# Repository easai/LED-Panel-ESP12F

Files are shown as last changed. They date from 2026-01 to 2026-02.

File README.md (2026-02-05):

# LED Panel ESP‑12F

The HTML page is available in this GitHub repository:
[https://easai.github.io/LED-Panel-ESP12F/](https://easai.github.io/LED-Panel-ESP12F/)

A compact ESP‑12F–based controller board designed to drive an 8×8 LED panel with an onboard buzzer, stable power regulation, and reliable programming support. This project was completed with the generous support of my sponsor, whose fabrication assistance transformed a fragile prototype into a robust, reproducible hardware platform.

## Sponsor Acknowledgment

This project reached completion thanks to the support of <a href="https://www.pcbway.com/" target="_blank" title="PCBWay">PCBWay</a>, who provided fabrication assistance that transformed the prototype into a clean, reliable PCB. Before fabrication, the prototype relied on a dense web of jumper wires, loose connections, and constant troubleshooting. With my sponsor’s help, the design moved from that unstable setup to a clean, professionally manufactured PCB that is easy to assemble, reliable to operate, and ready for long‑term use.

Their contribution directly improved electrical stability, mechanical reliability, assembly clarity, and long‑term maintainability. The contrast between the prototype and the final board demonstrates the real value of proper PCB fabrication.

## Breadboard Prototype → PCB Assembly

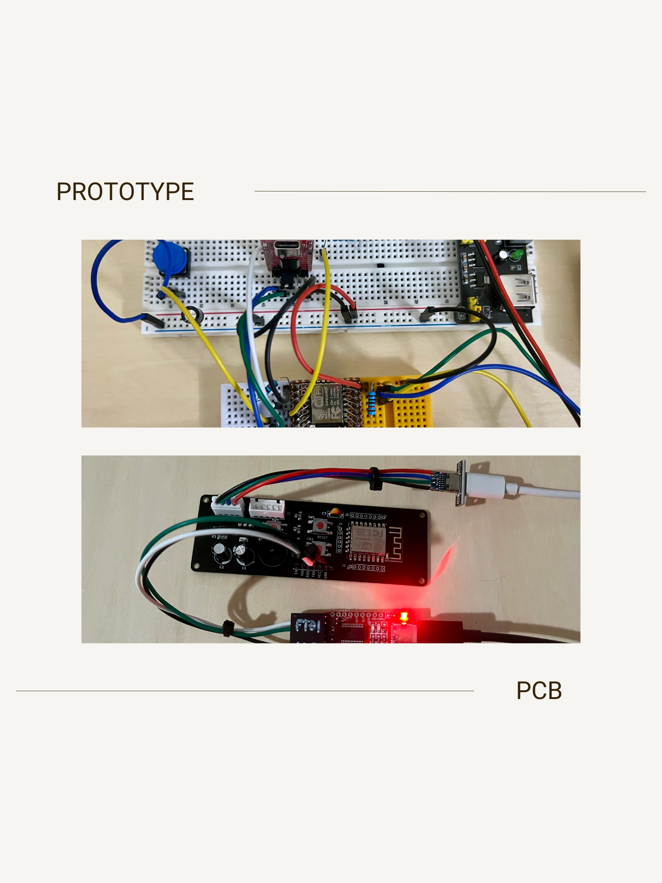
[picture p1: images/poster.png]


### Before: Breadboard-based Prototype  
The initial version worked, but the wiring was messy, fragile, and difficult to debug. It served its purpose for early validation, but it was not suitable for repeated use or documentation.  

<div class="flex">
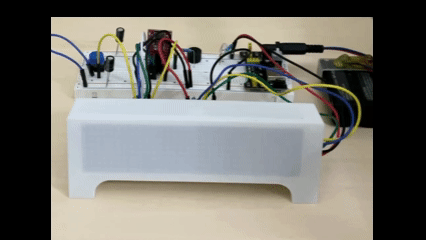
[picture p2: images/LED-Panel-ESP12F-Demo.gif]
LED Panel ESP12F Demo

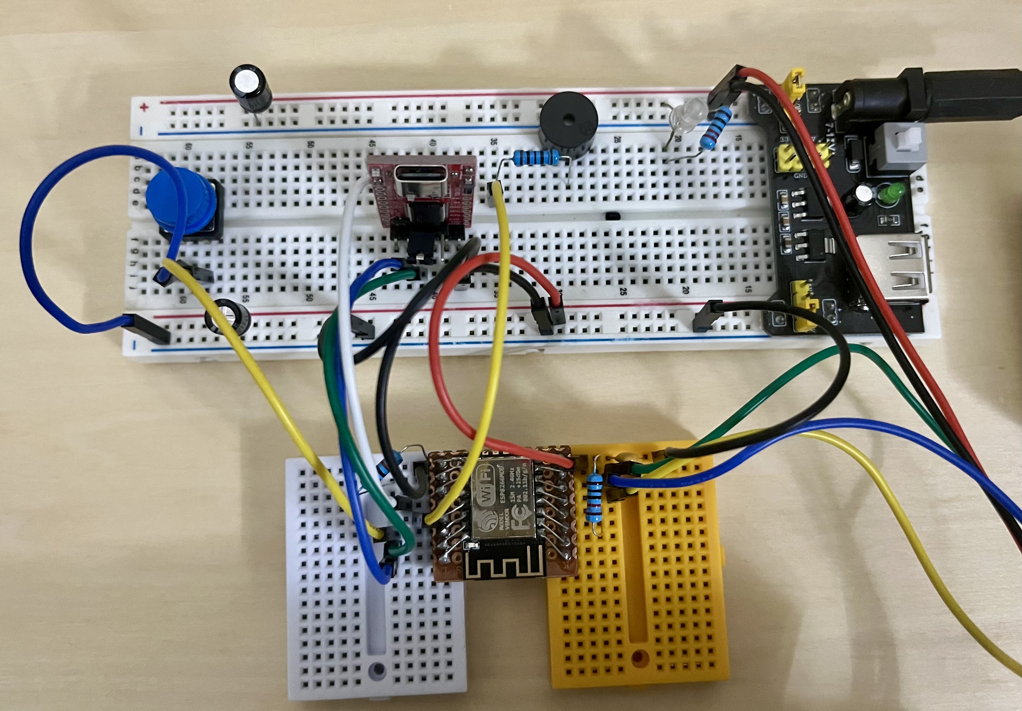
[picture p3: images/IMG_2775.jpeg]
LED-Panel-ESP12F Prototype

</div>

### After: Assembled PCB  
The final PCB was fabricated by PCBWay, whose manufacturing quality made the design stable, durable, and easy to assemble. The board programs correctly, executes firmware without issues, and drives the LED panel and buzzer exactly as intended.  

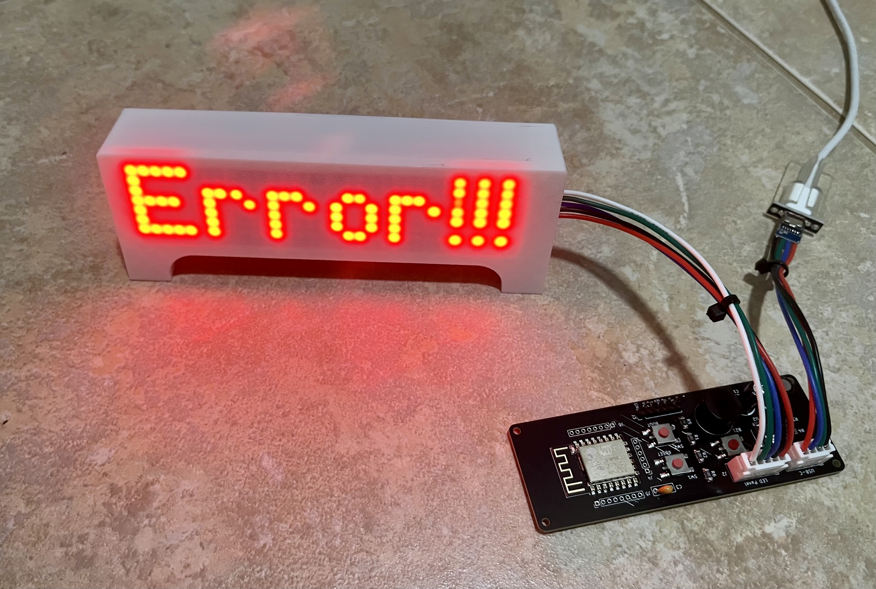
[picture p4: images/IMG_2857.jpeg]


This comparison highlights the impact of fabrication support and the improvement in overall quality.

## Programming the ESP‑12F Using an FTDI Adapter

The ESP‑12F can be programmed directly through a USB‑to‑serial adapter such as an FTDI module. The board includes a dedicated programming header, making the upload process reliable and repeatable.

To enter programming mode, the ESP‑12F requires specific boot pin states during reset. The PCB handles these automatically through pull‑ups and pull‑downs, so only four connections are needed from the FTDI adapter:

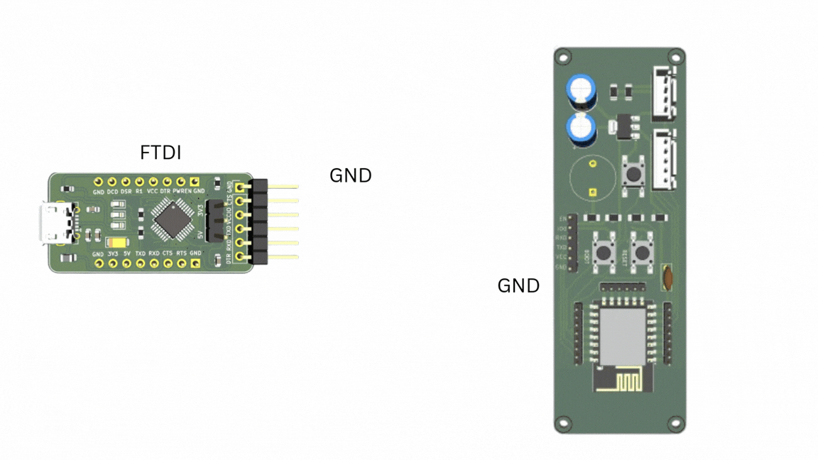
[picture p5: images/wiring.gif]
LED-Panel-ESP12F Programming the ESP‑12F Using an FTDI Adapter Wiring


Before uploading, connect the FTDI module to the programming header as shown below.

• FTDI TX → Programming header TX  
• FTDI RX → Programming header RX  
• FTDI GND → Programming header GND  

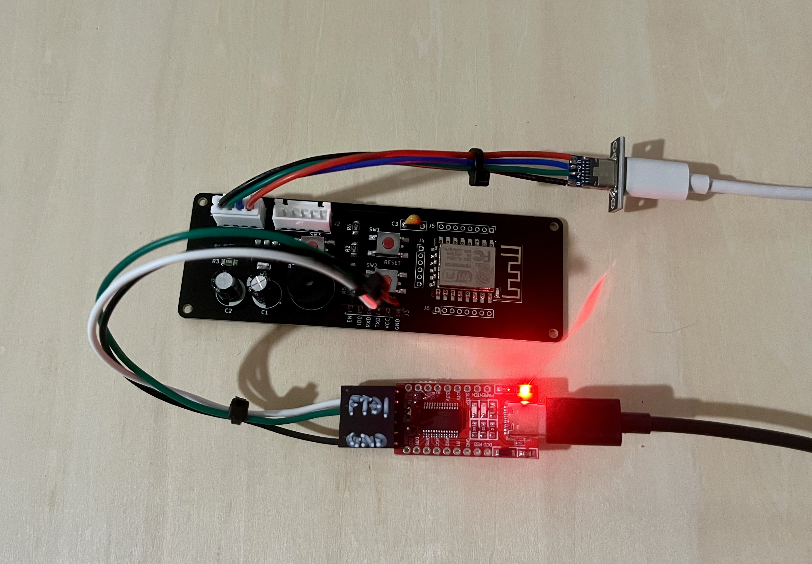
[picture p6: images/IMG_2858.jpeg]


Once connected:

1. Press and hold the BOOT button.  
2. Tap RESET.  
3. Release BOOT.  
4. Upload the firmware from your IDE (Arduino IDE or PlatformIO).  

The board will automatically reboot into normal operation after programming. This workflow ensures consistent flashing without the wiring errors common in breadboard prototypes.

## Configuration

Copy `config.h.sample` to `config.h` and fill in your network details.

`config.h` contains:
- `SECRET_SSID` for the WiFi network name
- `SECRET_PASS` for the WiFi password
- `SITE_URL` for the target endpoint

`config.h` is not tracked in the repository. Users must create it before building the firmware.

## Hardware Overview

The board integrates an ESP‑12F module, 5 V to 3.3 V regulation, LED panel connector, buzzer with mute control, programming header, clear silkscreen labeling, and a stable power and ground layout. All hardware files are included for reproducibility.

### Schematic
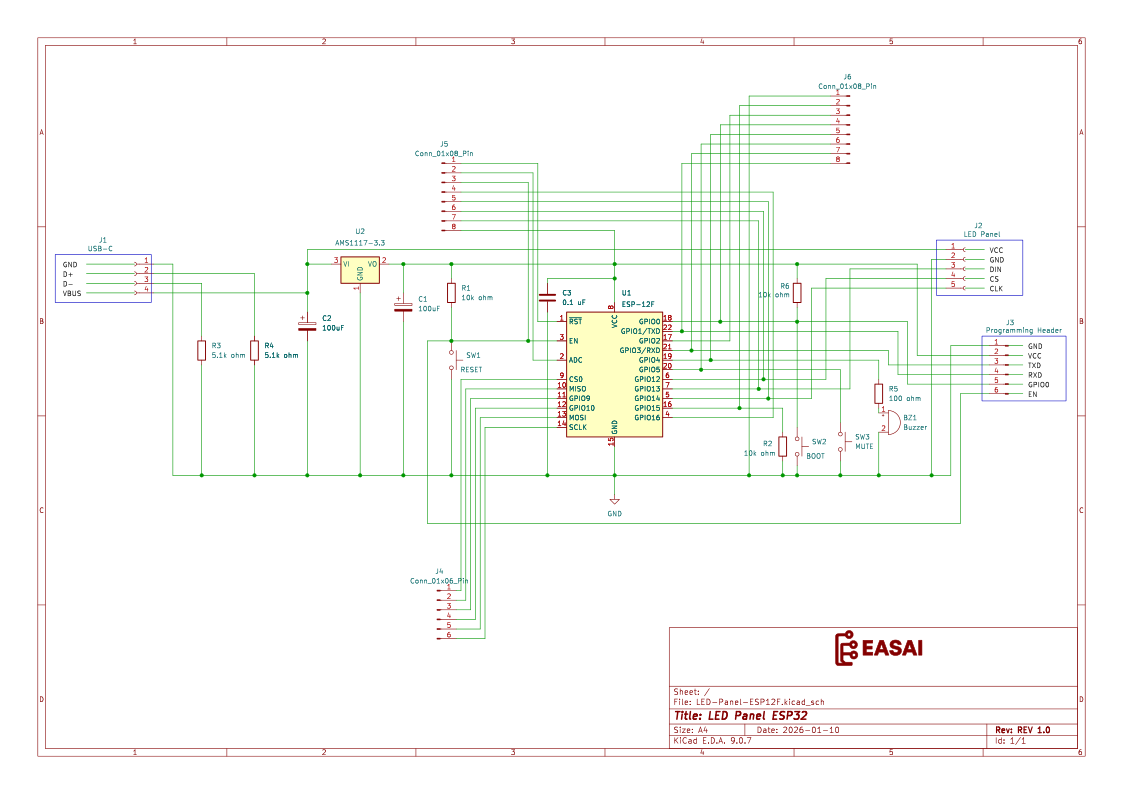
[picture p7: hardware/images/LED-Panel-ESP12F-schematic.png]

### Board Layout
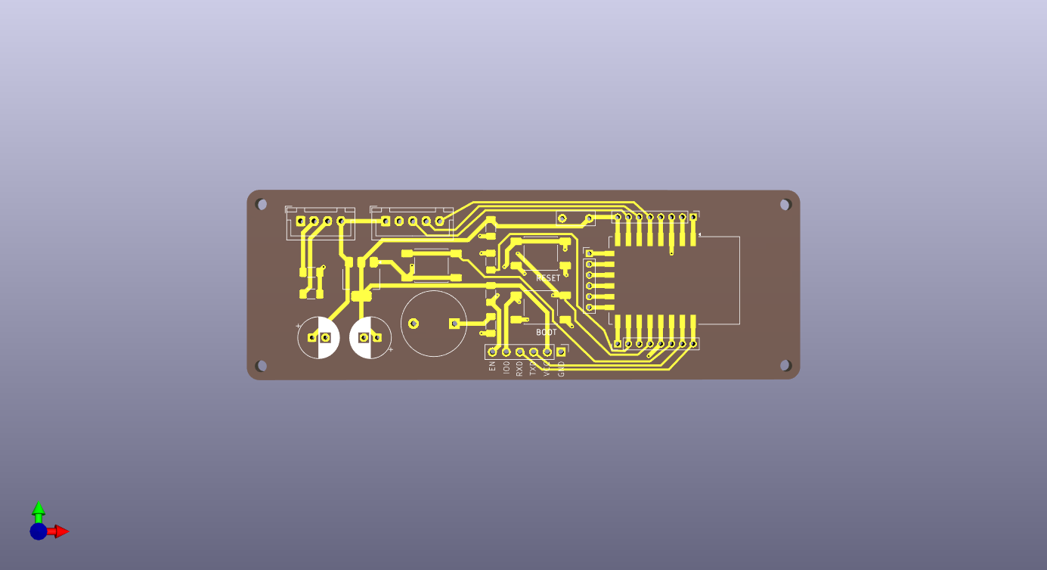
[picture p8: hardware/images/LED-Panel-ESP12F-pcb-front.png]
LED-Panel-ESP12F PCB Front

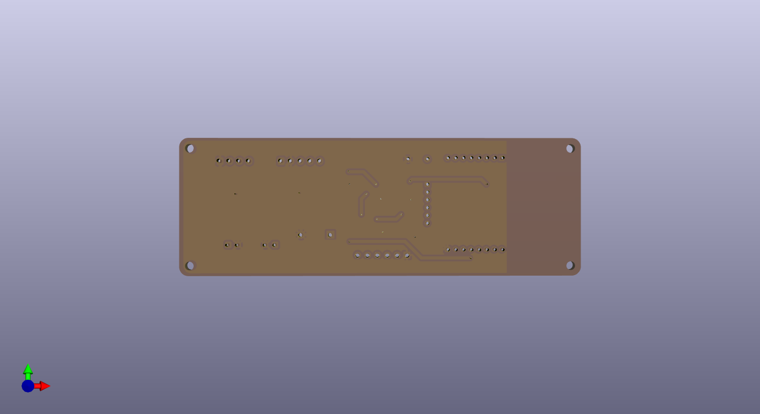
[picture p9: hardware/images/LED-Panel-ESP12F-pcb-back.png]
LED-Panel-ESP12F PCB Back

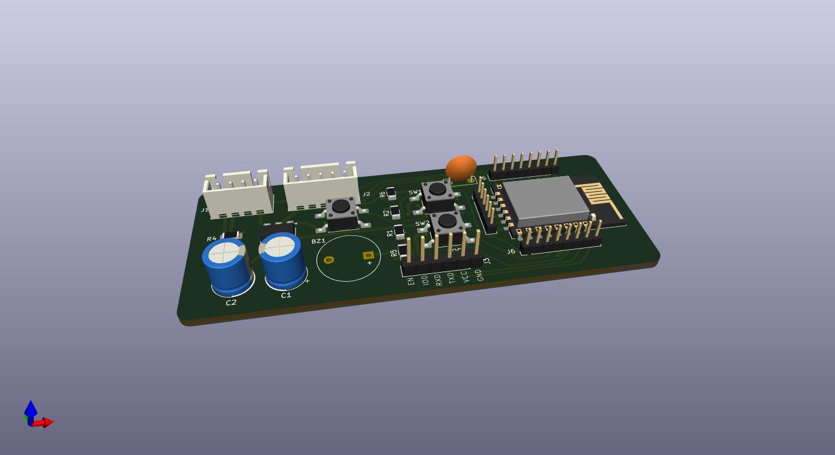
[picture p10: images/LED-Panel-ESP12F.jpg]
LED-Panel-ESP12F Assembled PCB


## Software

This firmware provides a stable demonstration of the ESP12F board and verifies that the PCB, power routing, and peripherals operate correctly. The program in main.cpp is structured around predictable, nonblocking timing and focuses on hardware validation rather than feature development.

### Boot and Initialization
The program configures all required GPIO pins for the LED panel, buzzer, mute switch, and status LED. It initializes the MAX7219 driver, clears the display, and starts serial output for debugging. This confirms that the ESP12F boots correctly after flashing.

### LED Panel Operation
The MAX7219 driver is initialized, and the panel is updated at fixed intervals using timestamp checks instead of delay. A simple pattern or text is shown to verify panel wiring, power stability, and refresh behavior. The update routine is nonblocking, so the device remains responsive.

### Buzzer and Mute Button
The buzzer is controlled through a digital output pin. The mute button is read continuously and suppresses buzzer output when pressed. This logic runs without blocking the main loop and confirms the correct routing of the switch and buzzer.

### WiFi Startup
WiFi initialization is included to confirm that the module boots into the correct mode and that RF components are functional. Connection status is printed to serial. No network features are implemented in this version.

### Main Loop Structure
The loop uses millisecond timestamps to schedule tasks. LED updates, button reads, and buzzer logic run at defined intervals. No blocking delays are used. This structure ensures reproducible behavior and provides a foundation for future animation or network features.

### Purpose of This Version
This firmware is intended for hardware validation. It confirms correct boot behavior, verifies the LED panel, buzzer, and button, and establishes a stable base for future development.

## Repository Structure

- hardware/kicad/ contains the KiCad schematic and PCB files  
- hardware/fabrication/ contains Gerbers, BOM
- hardware/images/ contains schematic, PCB front/back, prototype wiring, and assembled PCB images  
- README.md is this document

## Bill of Materials

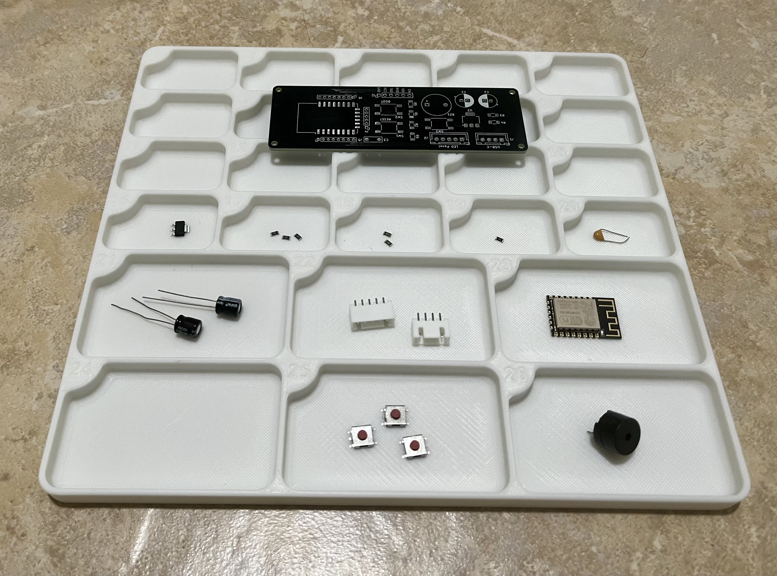
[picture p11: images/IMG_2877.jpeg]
LED Panel ESP12F Parts


A complete BOM is available in <a href="https://github.com/easai/LED-Panel-ESP12F/blob/main/hardware/fabrication/LED-Panel-ESP12F-bom.csv" target="_blank" title="LED-Panel-ESP12F BOM">hardware/fabrication/LED-Panel-ESP12F-bom.csv</a>.

## Credits

PCB fabrication provided by PCBWay.

The LED matrix case used in this project is my own remix, published at <a href="https://www.printables.com/" title="Printables.com" target="_blank">Printables</a>:  
<a href="https://www.printables.com/model/1476658-4-in-1-led-dot-matrix-mount" title="4-in-1 LED Dot Matrix Mount" target="_blank">4-in-1 LED Dot Matrix Mount</a>

## License

MIT License

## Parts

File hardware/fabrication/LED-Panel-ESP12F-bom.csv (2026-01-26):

Reference | Qty | Value | DNP | Exclude from BOM | Exclude from Board | Footprint | Datasheet
BZ1 | 1 | Buzzer |  |  |  | Buzzer_Beeper:MagneticBuzzer_StarMicronics_TMB | ~
C1,C2 | 2 | 100uF |  |  |  | Capacitor_THT:CP_Radial_D7.5mm_P2.50mm | ~
C3 | 1 | 0.1 uF |  |  |  | Capacitor_THT:C_Disc_D7.0mm_W2.5mm_P5.00mm | ~
J1 | 1 | USB-C |  |  |  | Connector_JST:JST_XH_B4B-XH-A_1x04_P2.50mm_Vertical | ~
J2 | 1 | LED Panel |  |  |  | Connector_JST:JST_XH_B5B-XH-A_1x05_P2.50mm_Vertical | ~
J3 | 1 | Programming Header |  |  |  | Connector_PinHeader_2.54mm:PinHeader_1x06_P2.54mm_Vertical | ~
J4 | 1 | Conn_01x06_Pin |  |  |  | Connector_PinHeader_2.00mm:PinHeader_1x06_P2.00mm_Vertical | ~
J5,J6 | 2 | Conn_01x08_Pin |  |  |  | Connector_PinHeader_2.00mm:PinHeader_1x08_P2.00mm_Vertical | ~
R1,R2,R6 | 3 | 10k ohm |  |  |  | Resistor_SMD:R_1206_3216Metric_Pad1.30x1.75mm_HandSolder | ~
R3,R4 | 2 | 5.1k ohm |  |  |  | Resistor_SMD:R_1206_3216Metric_Pad1.30x1.75mm_HandSolder | ~
R5 | 1 | 100 ohm |  |  |  | Resistor_SMD:R_1206_3216Metric_Pad1.30x1.75mm_HandSolder | ~
SW1 | 1 | RESET |  |  |  | Button_Switch_SMD:SW_Push_1P1T_NO_E-Switch_TL3301NxxxxxG | ~
SW2 | 1 | BOOT |  |  |  | Button_Switch_SMD:SW_Push_1P1T_NO_E-Switch_TL3301NxxxxxG | ~
SW3 | 1 | MUTE |  |  |  | Button_Switch_SMD:SW_Push_1P1T_NO_E-Switch_TL3301NxxxxxG | ~
U1 | 1 | ESP-12F |  |  |  | RF_Module:ESP-12E | http://wiki.ai-thinker.com/_media/esp8266/esp8266_series_modules_user_manual_v1.1.pdf
U2 | 1 | AMS1117-3.3 |  |  |  | Package_TO_SOT_SMD:SOT-223-3_TabPin2 | http://www.advanced-monolithic.com/pdf/ds1117.pdf

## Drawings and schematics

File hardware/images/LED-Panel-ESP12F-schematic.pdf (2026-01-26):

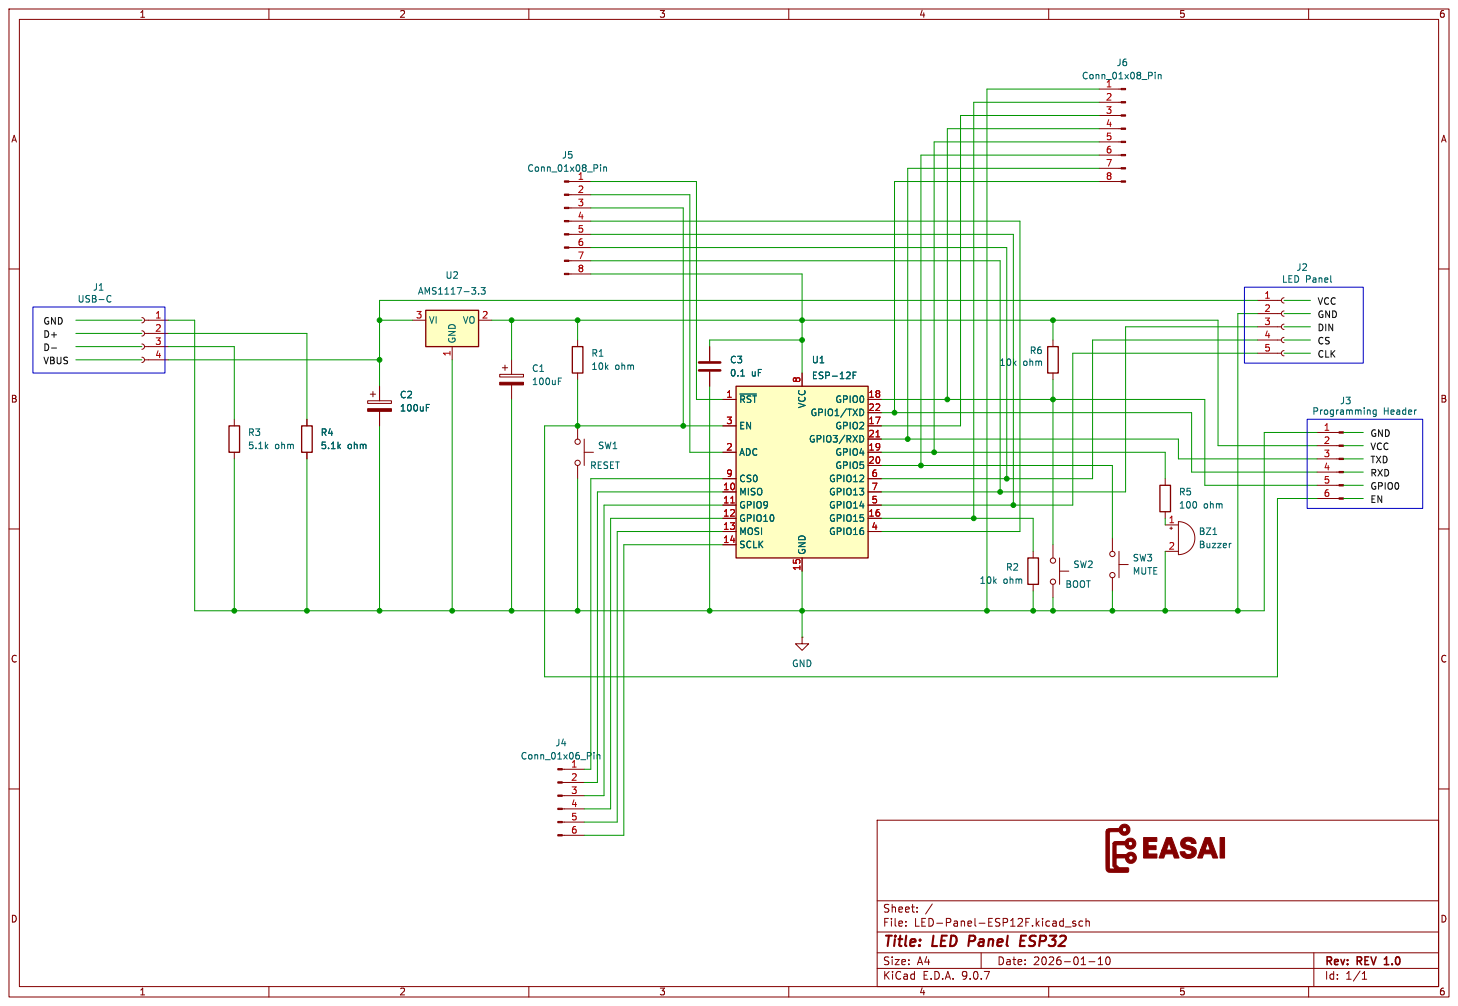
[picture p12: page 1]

File: LED-Panel-ESP12F.kicad_sch Sheet: /
Id: 1/1 Title: LED Panel ESP32

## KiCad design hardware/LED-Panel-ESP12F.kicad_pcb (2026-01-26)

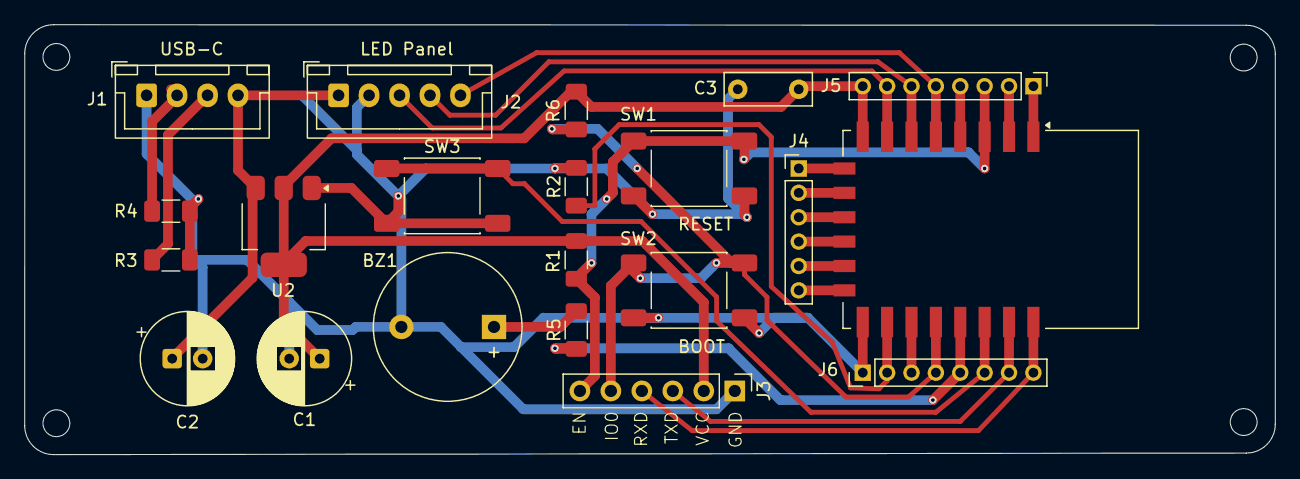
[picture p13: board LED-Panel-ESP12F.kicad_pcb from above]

Board: 2 copper layers, 102.6 x 35.3 mm, 21 parts (0 on the bottom side), 26 nets.

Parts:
BZ1: Buzzer; MagneticBuzzer_StarMicronics_TMB
C1, C2: 100uF; CP_Radial_D7.5mm_P2.50mm
C3: 0.1 uF; C_Disc_D7.0mm_W2.5mm_P5.00mm
J1: USB-C; JST_XH_B4B-XH-A_1x04_P2.50mm_Vertical
J2: LED Panel; JST_XH_B5B-XH-A_1x05_P2.50mm_Vertical
J3: Programming Header; PinHeader_1x06_P2.54mm_Vertical
J4: Conn_01x06_Pin; PinHeader_1x06_P2.00mm_Vertical
J5, J6: Conn_01x08_Pin; PinHeader_1x08_P2.00mm_Vertical
R1, R2, R6: 10k; R_1206_3216Metric_Pad1.30x1.75mm_HandSolder
R3, R4: 5.1k; R_1206_3216Metric_Pad1.30x1.75mm_HandSolder
R5: 100; R_1206_3216Metric_Pad1.30x1.75mm_HandSolder
SW1: RESET; SW_Push_1P1T_NO_E-Switch_TL3301NxxxxxG
SW2: BOOT; SW_Push_1P1T_NO_E-Switch_TL3301NxxxxxG
SW3: MUTE; SW_Push_1P1T_NO_E-Switch_TL3301NxxxxxG
U1: ESP-12F; ESP-12E
U2: AMS1117-3.3; SOT-223-3_TabPin2

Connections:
GND: BZ1.2 (-), C1.2, C2.2, C3.2, J1.1, J2.2, J3.1, J6.1, R2.2, R3.2, R4.2, SW1.2, SW2.2, SW3.2, U1.15 (GND), U2.1 (GND)
unnamed: BZ1.1 (+), R5.2
unnamed: J1.2, R4.1
unnamed: J1.3, R3.1
unnamed: C2.1, J1.4, J2.1, U2.3 (VI)
unnamed: J2.3, J5.7, U1.7 (GPIO13)
unnamed: J2.4, J5.6, U1.6 (GPIO12)
unnamed: J2.5, J5.5, U1.5 (GPIO14)
unnamed: C1.1, C3.1, J3.2, J5.8, R1.1, R6.1, U1.8 (VCC), U2.2 (VO)
unnamed: J3.3, J6.7, U1.21 (GPIO3/RXD)
unnamed: J3.4, J6.8, U1.22 (GPIO1/TXD)
unnamed: J3.5, J6.4, R6.2, SW2.1, U1.18 (GPIO0)
unnamed: J3.6, J5.3, R1.2, SW1.1, U1.3 (EN)
unnamed: J4.1, U1.9 (CS0)
unnamed: J4.2, U1.10 (MISO)
unnamed: J4.3, U1.11 (GPIO9)
unnamed: J4.4, U1.12 (GPIO10)
unnamed: J4.5, U1.13 (MOSI)
unnamed: J4.6, U1.14 (SCLK)
unnamed: J5.1, U1.1 (~RST)
unnamed: J5.2, U1.2 (ADC)
unnamed: J5.4, U1.4 (GPIO16)
unnamed: J6.2, R2.1, U1.16 (GPIO15)
unnamed: J6.3, U1.17 (GPIO2)
unnamed: J6.5, R5.1, U1.19 (GPIO4)
unnamed: J6.6, SW3.1, U1.20 (GPIO5)

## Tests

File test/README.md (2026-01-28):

# LED-Panel-ESP12F Unit Tests

Unit tests for the LED-Panel-ESP12F firmware using PlatformIO's Unity test framework.

## Test Files

| File | Description | Tests |
|---|---|---|
| `test_state.cpp` | State management, mute toggle, WiFi state | 18 |
| `test_http_codes.cpp` | HTTP response code interpretation | 32 |
| `test_timing.cpp` | Timing calculations, millis() overflow | 27 |

## Running Tests

### On ESP12E Hardware

```bash
# Run all tests
pio test -e esp12e_test

# Run a specific test file
pio test -e esp12e_test -f test_state
pio test -e esp12e_test -f test_http_codes
pio test -e esp12e_test -f test_timing
```

### Test Output

Tests output results via Serial at 115200 baud:

```
test/test_state.cpp:45:test_state_default_values:PASS
test/test_state.cpp:67:test_should_not_check_site_when_wifi_disconnected:PASS
...
-----------------------
18 Tests 0 Failures 0 Ignored
OK
```

## Test Coverage

### State Management (`test_state.cpp`)
- ✅ Default state initialization
- ✅ Site check timing conditions
- ✅ WiFi reconnection logic
- ✅ Button debounce behavior
- ✅ Mute toggle functionality
- ✅ Message buffer validation

### HTTP Codes (`test_http_codes.cpp`)
- ✅ Connection errors (negative codes)
- ✅ 1xx Informational responses
- ✅ 2xx Success responses
- ✅ 3xx Redirect responses
- ✅ 4xx Client error responses (server is up)
- ✅ 5xx Server error responses (server is down)

### Timing (`test_timing.cpp`)
- ✅ Basic elapsed time calculations
- ✅ Millis overflow handling (uint32_t wraparound)
- ✅ Interval checking
- ✅ Timeout detection
- ✅ Debounce timing

## Test Structure

Each test file follows PlatformIO's embedded test pattern:

```cpp
#include <Arduino.h>
#include <unity.h>

void setUp(void) {
    // Runs before each test
}

void tearDown(void) {
    // Runs after each test
}

void test_example(void) {
    TEST_ASSERT_TRUE(true);
}

void setup() {
    delay(2000);  // Allow board to settle
    UNITY_BEGIN();
    RUN_TEST(test_example);
    UNITY_END();
}

void loop() {
    // Empty
}
```

## Adding New Tests

1. Create `test/test_<feature>.cpp`
2. Include `<Arduino.h>` and `<unity.h>`
3. Add `setUp()` and `tearDown()` functions
4. Write test functions prefixed with `test_`
5. Add `setup()` with `UNITY_BEGIN()`, `RUN_TEST()` calls, `UNITY_END()`
6. Add empty `loop()`

## Mock Functions

For controlled timing tests, we use mock millis:

```cpp
static uint32_t mock_millis_value = 0;
uint32_t mock_millis() { return mock_millis_value; }
void set_mock_millis(uint32_t val) { mock_millis_value = val; }
```

This allows testing timing logic without waiting for real time to pass.

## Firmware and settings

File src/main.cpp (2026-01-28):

/**
 * LED-Panel-ESP12F - Optimized Firmware
 * 
 * Site monitoring with LED display and buzzer alerts
 * 
 * Optimizations:
 * - Reduced memory usage with PROGMEM strings
 * - Added WiFi reconnection handling
 * - Debounced mute button with timing
 * - Configurable check interval
 * - Better error handling and status codes
 * - Added serial debugging (optional)
 * - Power-efficient WiFi sleep between checks
 * - Visual feedback for mute state
 * - Watchdog timer for reliability
 */

#include <ESP8266WiFi.h>
#include <ESP8266HTTPClient.h>
#include <WiFiClientSecureBearSSL.h>
#include <MD_Parola.h>
#include <MD_MAX72XX.h>
#include <SPI.h>
#include "config.h"

// ============== Configuration ==============
#define HARDWARE_TYPE   MD_MAX72XX::FC16_HW
#define MAX_DEVICES     4
#define CS_PIN          12
#define BUZZ_PIN        4
#define MUTE_PIN        5

// Timing constants (in milliseconds)
constexpr uint32_t CHECK_INTERVAL     = 30000;   // Site check interval
constexpr uint32_t WIFI_TIMEOUT       = 15000;   // WiFi connection timeout
constexpr uint32_t HTTP_TIMEOUT       = 5000;    // HTTP request timeout
constexpr uint32_t DEBOUNCE_DELAY     = 200;     // Button debounce time
constexpr uint32_t RECONNECT_INTERVAL = 60000;   // WiFi reconnect attempt interval
constexpr uint32_t PING_DISPLAY_TIME  = 500;     // How long to show "PING"

// Display settings
constexpr uint8_t  DISPLAY_INTENSITY  = 2;       // 0-15
constexpr uint16_t SCROLL_SPEED       = 40;      // Lower = faster

// Debug mode (comment out to disable serial output)
#define DEBUG_MODE

#ifdef DEBUG_MODE
    #define DEBUG_PRINT(x)   Serial.print(x)
    #define DEBUG_PRINTLN(x) Serial.println(x)
#else
    #define DEBUG_PRINT(x)
    #define DEBUG_PRINTLN(x)
#endif

// ============== PROGMEM Strings ==============
const char MSG_WIFI_CONNECTING[] PROGMEM = "WiFi...";
const char MSG_WIFI_OK[]         PROGMEM = "WiFi OK";
const char MSG_WIFI_ERROR[]      PROGMEM = "WiFi Err";
const char MSG_WIFI_RECONNECT[]  PROGMEM = "Reconn...";
const char MSG_PING[]            PROGMEM = "Pinging";
const char MSG_MUTED[]           PROGMEM = "Muted";
const char MSG_UNMUTED[]         PROGMEM = "Sound On";

// Site status messages
const char MSG_SITE_UP[]   PROGMEM = "SITE OK";
const char MSG_SITE_DOWN[] PROGMEM = "SITE DOWN!";

// ============== Global State ==============
MD_Parola display = MD_Parola(HARDWARE_TYPE, CS_PIN, MAX_DEVICES);

// Volatile for ISR access
volatile bool muteToggleRequest = false;

// State variables
struct State {
    bool     isMuted          = false;
    bool     siteIsUp         = true;
    bool     wifiConnected    = false;
    bool     messageScrolling = false;
    uint32_t lastCheckTime    = 0;
    uint32_t lastReconnect    = 0;
    uint32_t lastButtonPress  = 0;
} state;

// Message buffer for PROGMEM strings
char msgBuffer[32];

// ============== Function Declarations ==============
void setupDisplay();
void setupWiFi();
void setupPins();
bool connectWiFi();
bool checkSiteStatus();
void handleMuteToggle();
void updateDisplay(const char* msg, bool fromProgmem = true);
void showStatus(bool isUp);
void playAlertTone(bool enable);
void checkWiFiConnection();

// ============== ISR ==============
void IRAM_ATTR onMuteButtonPress() {
    muteToggleRequest = true;
}

// ============== Setup ==============
void setup() {
#ifdef DEBUG_MODE
    Serial.begin(115200);
    delay(100);
    DEBUG_PRINTLN(F("\n\n=== LED-Panel-ESP12F ==="));
    DEBUG_PRINTLN(F("Optimized Firmware v2.0"));
#endif

    setupPins();
    setupDisplay();
    setupWiFi();
    
    // Initial site check after boot
    state.lastCheckTime = millis() - CHECK_INTERVAL + 5000; // Check 5s after boot
    
    DEBUG_PRINTLN(F("Setup complete"));
}

// ============== Main Loop ==============
void loop() {
    // Handle display animations
    if (display.displayAnimate()) {
        if (state.messageScrolling) {
            state.messageScrolling = false;
            display.displayClear();
        }
    }
    
    // Handle mute button (with debounce)
    if (muteToggleRequest) {
        handleMuteToggle();
    }
    
    // Check WiFi connection periodically
    checkWiFiConnection();
    
    // Periodic site check
    uint32_t now = millis();
    if (state.wifiConnected && (now - state.lastCheckTime >= CHECK_INTERVAL)) {
        state.lastCheckTime = now;
        
        // Show PING indicator
        updateDisplay(MSG_PING);
        display.displayText(msgBuffer, PA_CENTER, 0, PING_DISPLAY_TIME, PA_PRINT, PA_NO_EFFECT);
        display.displayAnimate();
        delay(PING_DISPLAY_TIME);
        
        // Check site
        DEBUG_PRINT(F("Checking site... "));
        bool isUp = checkSiteStatus();
        DEBUG_PRINTLN(isUp ? F("UP") : F("DOWN"));
        
        // Update state and display
        state.siteIsUp = isUp;
        
        showStatus(isUp);
        
        // Alert on status change or if down
        if (!isUp) {
            playAlertTone(!state.isMuted);
        } else {
            playAlertTone(false);
        }
    }
    
    // Small delay to prevent tight loop
    delay(10);
}

// ============== Implementation ==============

void setupPins() {
    pinMode(BUZZ_PIN, OUTPUT);
    pinMode(MUTE_PIN, INPUT_PULLUP);
    digitalWrite(BUZZ_PIN, LOW);
    
    attachInterrupt(digitalPinToInterrupt(MUTE_PIN), onMuteButtonPress, FALLING);
    
    DEBUG_PRINTLN(F("Pins configured"));
}

void setupDisplay() {
    display.begin();
    display.setIntensity(DISPLAY_INTENSITY);
    display.displayClear();
    display.setTextAlignment(PA_CENTER);
    
    DEBUG_PRINTLN(F("Display initialized"));
}

void setupWiFi() {
    WiFi.mode(WIFI_STA);
    WiFi.setAutoReconnect(true);
    WiFi.persistent(false);  // Don't save to flash (reduces wear)
    
    updateDisplay(MSG_WIFI_CONNECTING);
    display.displayText(msgBuffer, PA_CENTER, SCROLL_SPEED, 0, PA_SCROLL_LEFT, PA_SCROLL_LEFT);
    
    state.wifiConnected = connectWiFi();
    
    if (state.wifiConnected) {
        updateDisplay(MSG_WIFI_OK);
        DEBUG_PRINT(F("Connected! IP: "));
        DEBUG_PRINTLN(WiFi.localIP());
    } else {
        updateDisplay(MSG_WIFI_ERROR);
        playAlertTone(true);
        delay(1000);
        playAlertTone(false);
        DEBUG_PRINTLN(F("WiFi connection failed"));
    }
    
    // Show message briefly
    display.displayText(msgBuffer, PA_CENTER, SCROLL_SPEED, 2000, PA_SCROLL_LEFT, PA_NO_EFFECT);
    state.messageScrolling = true;
}

bool connectWiFi() {
    WiFi.begin(SECRET_SSID, SECRET_PASS);
    
    uint32_t startTime = millis();
    while (WiFi.status() != WL_CONNECTED) {
        if (millis() - startTime >= WIFI_TIMEOUT) {
            return false;
        }
        delay(100);
        
        // Keep display animating during connection
        display.displayAnimate();
    }
    
    return true;
}

void checkWiFiConnection() {
    bool connected = (WiFi.status() == WL_CONNECTED);
    
    if (!connected && state.wifiConnected) {
        // Lost connection
        DEBUG_PRINTLN(F("WiFi disconnected!"));
        state.wifiConnected = false;
        playAlertTone(!state.isMuted);
    }
    
    // Attempt reconnect periodically
    if (!connected) {
        uint32_t now = millis();
        if (now - state.lastReconnect >= RECONNECT_INTERVAL) {
            state.lastReconnect = now;
            DEBUG_PRINTLN(F("Attempting WiFi reconnect..."));
            
            updateDisplay(MSG_WIFI_RECONNECT);
            display.displayText(msgBuffer, PA_CENTER, SCROLL_SPEED, 0, PA_SCROLL_LEFT, PA_NO_EFFECT);
            
            WiFi.reconnect();
            delay(5000);  // Give it time
            
            if (WiFi.status() == WL_CONNECTED) {
                state.wifiConnected = true;
                playAlertTone(false);
                DEBUG_PRINTLN(F("Reconnected!"));
            }
        }
    }
}

bool checkSiteStatus() {
    // Use BearSSL for secure connection
    std::unique_ptr<BearSSL::WiFiClientSecure> client(new BearSSL::WiFiClientSecure);
    client->setInsecure();  // Skip certificate verification
    
    HTTPClient http;
    http.setTimeout(HTTP_TIMEOUT);
    http.setFollowRedirects(HTTPC_STRICT_FOLLOW_REDIRECTS);
    
    if (!http.begin(*client, SITE_URL)) {
        DEBUG_PRINTLN(F("HTTP begin failed"));
        return false;
    }
    
    // Add headers for better compatibility
    http.addHeader("User-Agent", "ESP8266-Monitor/2.0");
    http.addHeader("Connection", "close");
    
    int httpCode = http.GET();
    http.end();
    
    DEBUG_PRINT(F("HTTP code: "));
    DEBUG_PRINTLN(httpCode);
    
    // Consider 2xx and 3xx as "up"
    // 4xx client errors might still mean server is responding
    // 5xx server errors = down
    if (httpCode < 0) {
        return false;  // Connection error
    }
    
    return (httpCode < 500);
}

void handleMuteToggle() {
    uint32_t now = millis();
    
    // Debounce
    if (now - state.lastButtonPress < DEBOUNCE_DELAY) {
        muteToggleRequest = false;
        return;
    }
    
    state.lastButtonPress = now;
    muteToggleRequest = false;
    
    // Toggle mute state
    state.isMuted = !state.isMuted;
    
    DEBUG_PRINT(F("Mute toggled: "));
    DEBUG_PRINTLN(state.isMuted ? F("ON") : F("OFF"));
    
    // Stop any playing tone
    if (state.isMuted) {
        noTone(BUZZ_PIN);
        updateDisplay(MSG_MUTED);
    } else {
        updateDisplay(MSG_UNMUTED);
        // Brief confirmation beep
        tone(BUZZ_PIN, 1000, 100);
    }
    
    // Show mute status briefly
    display.displayText(msgBuffer, PA_CENTER, SCROLL_SPEED, 1500, PA_SCROLL_LEFT, PA_NO_EFFECT);
    state.messageScrolling = true;
}

void updateDisplay(const char* msg, bool fromProgmem) {
    if (fromProgmem) {
        strcpy_P(msgBuffer, msg);
    } else {
        strncpy(msgBuffer, msg, sizeof(msgBuffer) - 1);
        msgBuffer[sizeof(msgBuffer) - 1] = '\0';
    }
}

void showStatus(bool isUp) {
    if (isUp) {
        updateDisplay(MSG_SITE_UP);
    } else {
        updateDisplay(MSG_SITE_DOWN);
    }
    
    display.displayText(msgBuffer, PA_CENTER, SCROLL_SPEED, 0, PA_SCROLL_LEFT, PA_SCROLL_LEFT);
    state.messageScrolling = true;
}

void playAlertTone(bool enable) {
    if (enable) {
        tone(BUZZ_PIN, 2000);
    } else {
        noTone(BUZZ_PIN);
    }
}

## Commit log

2026-01-13 add pcb image
2026-01-26 Add hardware files
    [LED-Panel-ESP12F-bom.csv, LED-Panel-ESP12F.kicad_pcb, LED-Panel-ESP12F.kicad_sch]
2026-01-26 Add schematic PNG
2026-01-26 Update README with schematic and board layout
    Added schematic and board layout images to README.
2026-01-26 Add assembled PCB image to README
    Added image of assembled PCB to the README.
2026-01-28 Add config.h.sample.
2026-02-02 Add wiring GIF
2026-02-02 Update README with FTDI adapter programming details
    Added wiring diagram and connection instructions for FTDI adapter.
2026-02-02 Update wiring GIF
2026-02-02 Enhance README with images of prototypes
    Added images to illustrate the breadboard prototype and final PCB.
2026-02-05 Enhance README with prototype image and details
    Added an image and description of the breadboard-based prototype.
2026-02-05 Update section title from 'Before and After' to 'From breadboard prototype to PCB'
2026-02-05 Change section title from 'From breadboard prototype to PCB' to 'Breadboard Prototype → PCB Assembly'
    Updated section title for clarity and consistency.
2026-02-05 Replace prototype image with final PCB image
    Updated image in README to reflect final PCB assembly.
